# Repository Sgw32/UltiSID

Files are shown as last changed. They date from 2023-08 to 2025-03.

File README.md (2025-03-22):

# UltiSID

**Project name is now changed to KungFuSID:
https://github.com/Sgw32/KungFuSID

Open source SID 8580/6581 emulator that can be executed on Kung Fu Flash and new Kung Fu SID hardware

License - GNU General Public License v3 (derived from Bakisha STM32 SID player)

## Introduction

Project is heavily inspired by __SwinSID__ and __ArmSID__ project. And is maintained as an open-source alternative to them.
Now it is even working on a GD32F405RGT6 on 168 MHz with 8 MHz crystal, just like Kung Fu Flash - and firmware is using critical code from KFF. 
I'm looking for contributers(I can even pay for the work) who will add some assembler optimization magic into SID code. 

## Credits and special thanks:

* Tolaemon's NanoSwinSID page with open-hardware PCB available: http://www.tolaemon.com/nss/ 
My PCB is a modified version of SwinSID PCB

* ArmSID page with schematic: https://www.nobomi.cz/8bit/armsid/index_en.php
* Teensy SID emulator (huuuge, not really good): https://www.pjrc.com/c64-sid-chip-replacement/ and https://github.com/kokotisp/6581-SID-teensy
* SID BluePill emulators:
https://github.com/Bakisha/STM32-SID-PLAYER - my code is 80% based on this repository
https://github.com/dkm1978/BluePillSid - references
* Swinkels page - dead http://www.swinkels.tvtom.pl/swinsid/
Available on Archive.org - please check it, there is a SID emulation source for SwinSID atmega8515.
* Kung Fu Flash - https://github.com/KimJorgensen/KungFuFlash
I am inspired by simplicity of it and its power. 
* Pavel Myasnikov
Author of KungFuSID hardware design 
* Special greetings to Protovision Games

## Future plans

STM32F103 has a very long delay between CS fall down and interrupt routine begin - about 200ns. With a 500 ns window at all. 
I plan migrating to STM32F405RCT6(still, very cheap on Aliexpress) my PCB also supports it. Also, I should optimize RW&CS routines to enhance performance.

## Limitations

* ADSR attack works somewhat slow
* Data readings are not correct at event-intensive tunes(where there are a lot of write-to-SID activities)
* No 6581/8580 switch
* No paddles(can be done though)

## Support us

Crypto: 
0xeDc17cb23241eACe19DF3617291aa7d2d92E62DC (ETH, USDT ERC20)
Buy something here (3d models):
https://www.cgtrader.com/sgw32

## Video(and audio) 

## New video:
https://youtube.com/shorts/YMMjhMZqSjQ?feature=share

Old video:

UltiSID (https://www.youtube.com/watch?v=_ROxem-S0Jo)

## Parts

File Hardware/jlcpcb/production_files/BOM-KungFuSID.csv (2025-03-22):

Comment | Designator | Footprint | LCSC
1.2k | R3 | R_0402_1005Metric | C25867
6.2k | R2 | R_0402_1005Metric | C4260
20p | C10,C11 | C_0402_1005Metric | C1555
10u | C1,C2 | C_0402_1005Metric | C15525
100n | C3,C4,C5,C6,C7,C8,C9 | C_0402_1005Metric | C307331
2.2u | C12,C13 | C_0402_1005Metric | C170151
1N4148WS | D2 | D_SOD-323 | C2128
100 | R1,R4 | R_0402_1005Metric | C25076
33 | R9 | R_0402_1005Metric | C25105
470 | R7 | R_0402_1005Metric | C25117
510R | R5 | R_0402_1005Metric | C25123
10k | R6 | R_0402_1005Metric | C25744
1k | R8 | R_0402_1005Metric | C11702
0 | R10 | R_0402_1005Metric | C17168
LED | D1 | LED_0402_1005Metric | C434446
100R | RN1,RN2 | R_Array_Concave_4x0402 | C48442
AMS1117-3.3 | U1 | SOT-89-3 | C880752
8MHz | Y1 | Crystal_SMD_3225-2Pin_3.2x2.5mm | C889706
LM321 | U4 | SOT-23-5 | C9405
GD32F405RGT6 | U3 | LQFP-64_10x10mm_P0.5mm | C99031
C64-SID-Socket-hackup | U2 | DIP-28_W15.24mm
SWD | J1 | PinHeader_1x02_P2.54mm_Vertical

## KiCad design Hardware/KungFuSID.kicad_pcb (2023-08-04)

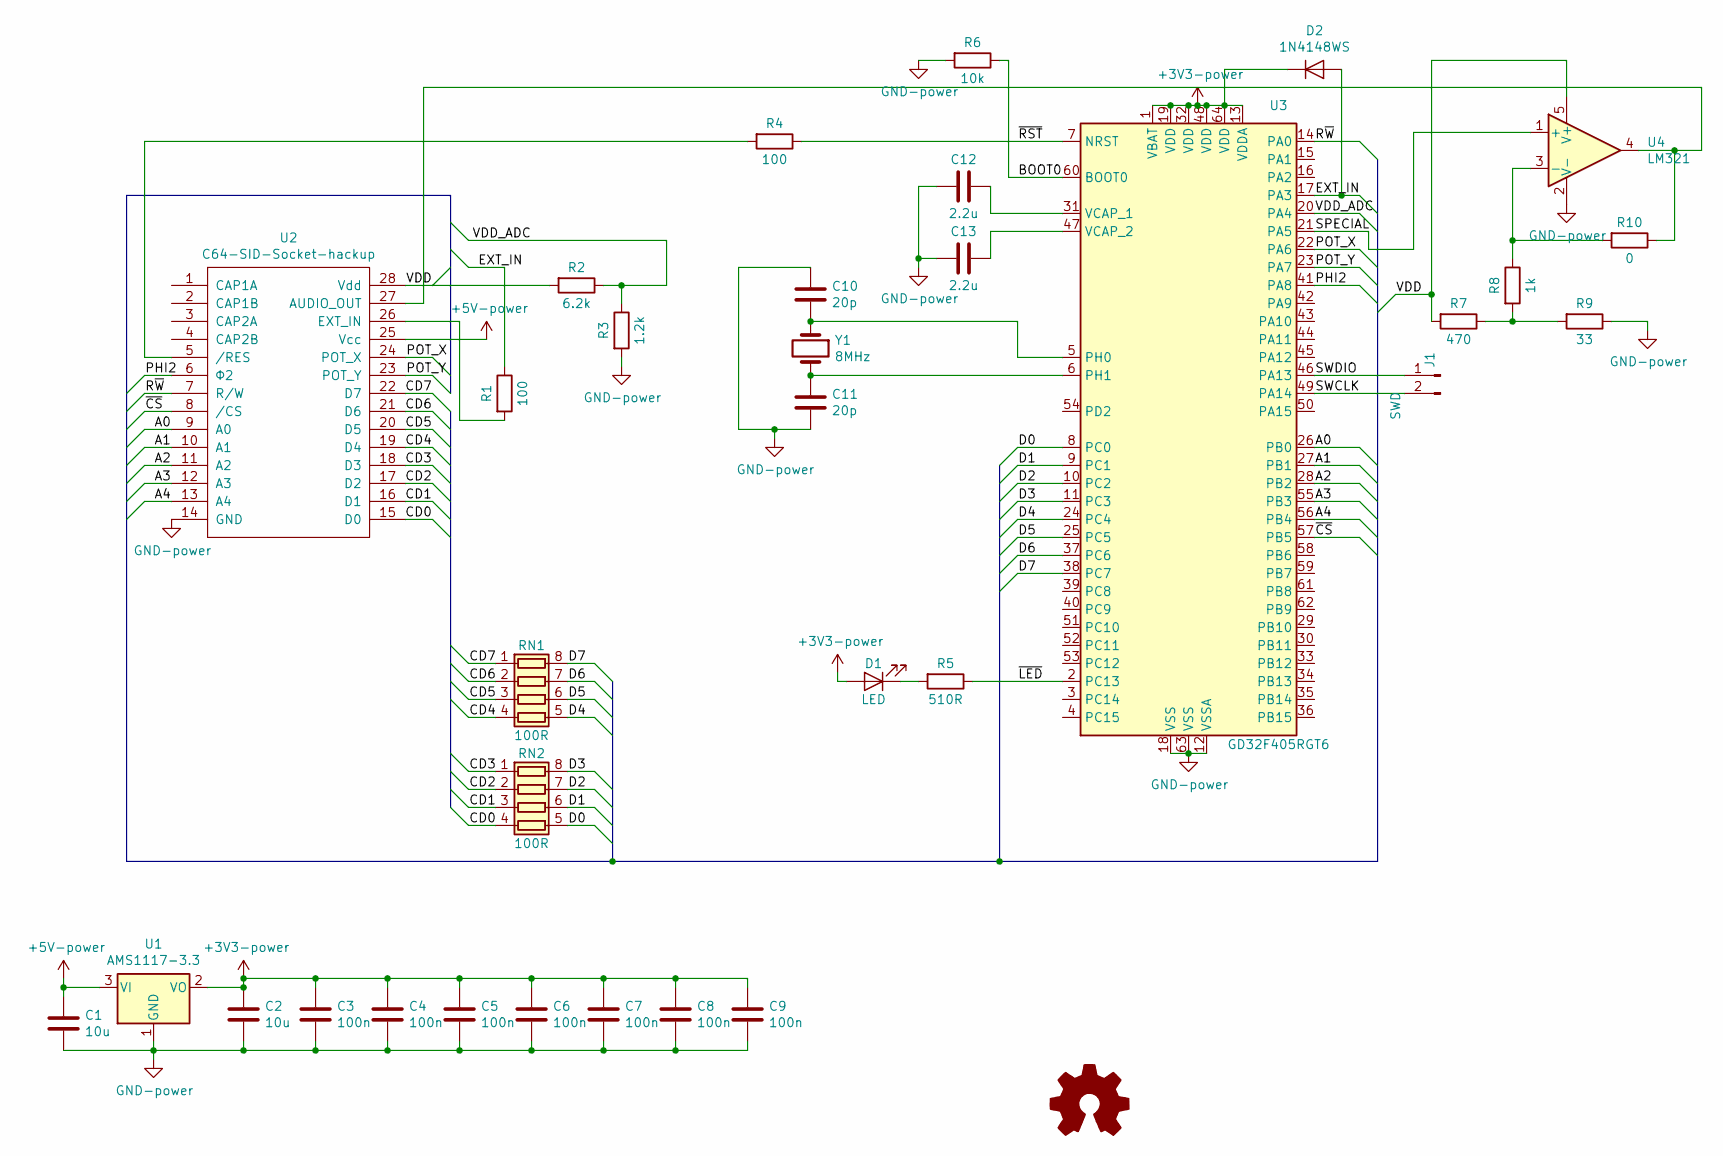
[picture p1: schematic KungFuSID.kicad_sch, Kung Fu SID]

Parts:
C1, C2: 10u; C_0402_1005Metric
C3, C4, C5, C6, C7, C8, C9: 100n; C_0402_1005Metric
C10, C11: 20p; C_0402_1005Metric
C12, C13: 2.2u; C_0402_1005Metric
D1: LED; LED_0402_1005Metric
D2: 1N4148WS; D_SOD-323
J1: SWD; PinHeader_1x02_P2.54mm_Vertical
R1, R4: 100; R_0402_1005Metric
R2: 6.2k; R_0402_1005Metric
R3: 1.2k; R_0402_1005Metric
R5: 510R; R_0402_1005Metric
R6: 10k; R_0402_1005Metric
R7: 470; R_0402_1005Metric
R8: 1k; R_0402_1005Metric
R9: 33; R_0402_1005Metric
R10: 0; R_0402_1005Metric
RN1, RN2: 100R; R_Array_Concave_4x0402
U1: AMS1117-3.3; SOT-89-3
U2: C64-SID-Socket-hackup; DIP-28_W15.24mm
U3: GD32F405RGT6; LQFP-64_10x10mm_P0.5mm
U4: LM321; SOT-23-5
Y1: 8MHz; Crystal_SMD_3225-2Pin_3.2x2.5mm

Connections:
+3V3: C2.1, C3.1, C4.1, C5.1, C6.1, C7.1, C8.1, C9.1, D1.2 (A), D2.1 (K), U1.2 (VO), U3.1 (VBAT), U3.13 (VDDA), U3.19 (VDD), U3.32 (VDD), U3.48 (VDD), U3.64 (VDD)
+5V: C1.1, U1.3 (VI), U2.25 (Vcc)
/A0: U2.9 (A0), U3.26 (PB0)
/A1: U2.10 (A1), U3.27 (PB1)
/A2: U2.11 (A2), U3.28 (PB2)
/A3: U2.12 (A3), U3.55 (PB3)
/A4: U2.13 (A4), U3.56 (PB4)
/BOOT0: R6.1, U3.60 (BOOT0)
/CD0: RN2.4 (R4.1), U2.15 (D0)
/CD1: RN2.3 (R3.1), U2.16 (D1)
/CD2: RN2.2 (R2.1), U2.17 (D2)
/CD3: RN2.1 (R1.1), U2.18 (D3)
/CD4: RN1.4 (R4.1), U2.19 (D4)
/CD5: RN1.3 (R3.1), U2.20 (D5)
/CD6: RN1.2 (R2.1), U2.21 (D6)
/CD7: RN1.1 (R1.1), U2.22 (D7)
/D0: RN2.5 (R4.2), U3.8 (PC0)
/D1: RN2.6 (R3.2), U3.9 (PC1)
/D2: RN2.7 (R2.2), U3.10 (PC2)
/D3: RN2.8 (R1.2), U3.11 (PC3)
/D4: RN1.5 (R4.2), U3.24 (PC4)
/D5: RN1.6 (R3.2), U3.25 (PC5)
/D6: RN1.7 (R2.2), U3.37 (PC6)
/D7: RN1.8 (R1.2), U3.38 (PC7)
/EXT_IN: D2.2 (A), R1.1, U3.17 (PA3)
/PHI2: U2.6 (Φ2), U3.41 (PA8)
/POT_X: U2.24 (POT_X), U3.22 (PA6)
/POT_Y: U2.23 (POT_Y), U3.23 (PA7)
/R~W: U2.7 (R/W), U3.14 (PA0)
/SPECIAL: U3.21 (PA5), U4.1 (+)
/SWCLK: J1.2, U3.49 (PA14)
/SWDIO: J1.1, U3.46 (PA13)
/VDD: R2.2, R7.2, U2.28 (Vdd), U4.5 (V+)
/VDD_ADC: R2.1, R3.1, U3.20 (PA4)
/~CS: U2.8 (/CS), U3.57 (PB5)
/~LED: R5.1, U3.2 (PC13)
/~RST: R4.1, U3.7 (NRST)
GND: C1.2, C2.2, C3.2, C4.2, C5.2, C6.2, C7.2, C8.2, C9.2, C10.1, C11.2, C12.1, C13.2, R3.2, R6.2, R9.1, U1.1 (GND), U2.14 (GND), U3.12 (VSSA), U3.18 (VSS), U3.63 (VSS), U4.2 (V-)
unnamed: C10.2, U3.5 (PH0), Y1.1
unnamed: C11.1, U3.6 (PH1), Y1.2
unnamed: C12.2, U3.31 (VCAP_1)
unnamed: C13.1, U3.47 (VCAP_2)
unnamed: D1.1 (K), R5.2
unnamed: R1.2, U2.26 (EXT_IN)
unnamed: R4.2, U2.5 (/RES)
unnamed: R7.1, R8.2, R9.2
unnamed: R10.1, U2.27 (AUDIO_OUT), U4.4
unnamed: R8.1, R10.2, U4.3 (-)

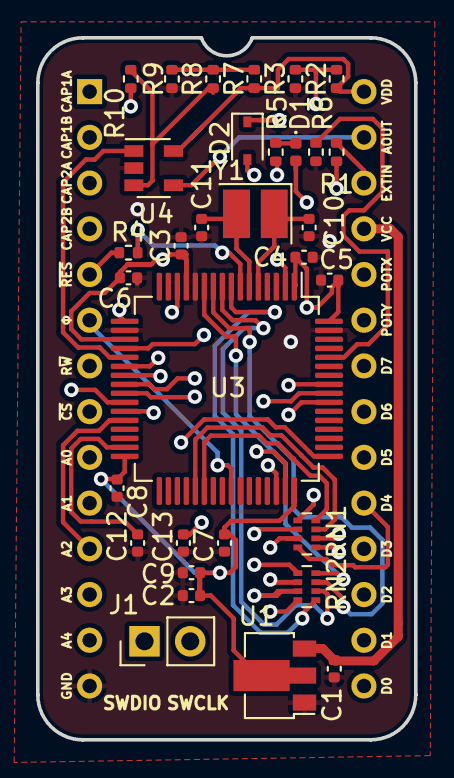
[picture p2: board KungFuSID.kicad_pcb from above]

Board: 4 copper layers, 21.0 x 39.0 mm, 33 parts (0 on the bottom side), 48 nets.

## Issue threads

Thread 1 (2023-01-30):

Question about Gerber/PCB

mwedmark, 2023-01-30:
Hello,

Are you ready to release PCB/Gerbers for this project? What is the current state of the project? How is thefunction compared to SwinSID? Are there any low-hanging fruit to upgrade this? Are there any reason for this 128Mhz project to be any worse than a 16Mhz MEGA emulator?

Lalarian, 2023-01-30:
Sadly it seems the author is no longer active. You can find some information here: https://www.forum64.de/index.php?thread/113715-ultisid-new-stm32-sid-chip-replacement/

Sgw32, 2023-01-30:
Hi. No, I'm here :)
Project is just suspended because I have a lot of other tasks, related to other projects. If you have something to contribute - welcome.
Current state is that it works with minor glitches in most of tunes. I need to fix it somehow, by using STM32F405 or something else. I just do not see open-source interest to this project from community, and I do not have a in-depth knowledge of STM32. Anyway, the best solution is probably to use Kung Fu Flash to debug this project. And use its address/data code to continue working on it. I may return to this, but first I need to finish some of my crowdfunding projects, related to Amiga and related to retro cars topic.
Anyway, stay tuned and good luck!

I also can release PCB and Gerbers since they will be heavily modified and they have issues that need to be fixed first.

Where is 16 MHz MEGA emulator? sounds interesting.
However, using 128 MHz is only because it latency of getting Address/Data bus is very-very high in comparison to even AVR. So, we need to do it much faster. Here it even uses a buffer of commands -which should not be here, because it's not a true realtime solution.

Also I can pay money if someone can achieve results on this project/ finally release it.

mwedmark, 2023-01-30:
Thanks for you prompt answer! Yea I just happen to have a good amount of Kung Fu Flashes (built some) so thanks for that idea. Sorry to see low interest, think it is a great idea to leave MEGAAVR for this newer tech. (What I've meant with MEGA emulator was really SwinSID.. I think it actually uses 32Mhz).

One idea of mine would be to team up with/cross-breed with this project: https://codeberg.org/CBMretro/PicoSID
Resonable starting-point for a HW RP2040-based SID. Currently without software which you seem to have here! :-) Maybe the usage of PIO's/DMA would make the latecy much less prominent. Would there be any reason for that HW-platform being worse that what you have here? Pity it is not in SID-format but bigger. I could probably be optimized into a double-sided PCB with components place on both sides. Tried it briefly but doubled the production cost...

Sgw32, 2023-02-26:
Hi everyone. Hardware published. Please do not order it until address lines are connected properly. But it is enough to use it as a reference.

Closed 2023-02-26.

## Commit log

2021-04-15 Initial commit - we have data on input but need circular buffer for it
    [100ask-openjtag.cfg, New_configuration.cfg, actux3.cfg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]
2021-04-19 Working with errors and some missing signals - not enough performance under 128 MHz. Will try more. Switched to Keil software from SW4, because SW4 had some problems in "extern" logic.
2021-04-19 Add schematic
2023-02-26 Add hardware
    [PowerBoard.SchDoc, ProgrammerConector.SchDoc, UltiSID.PcbDoc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]
2023-02-26 Add PCAD ASCII PCB file + PDF
2023-08-04 New UltiSID hardware - KungFuSID. Release version of UltiSID
    [BOM-KungFuSID.csv, KungFuSID.kicad_pcb, KungFuSID.kicad_sch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]
2023-10-07 Schematic-to-JLCPCB BOM bug fixed
    [BOM-KungFuSID.csv]
2025-03-22 Updated BOM
    [BOM-KungFuSID.csv]
